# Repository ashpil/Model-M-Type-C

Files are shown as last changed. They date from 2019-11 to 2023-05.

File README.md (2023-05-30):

# Model M Type C
This is a project with the simple goal of recreating the old IBM Model M keyboard controller with modern technologies in mind.

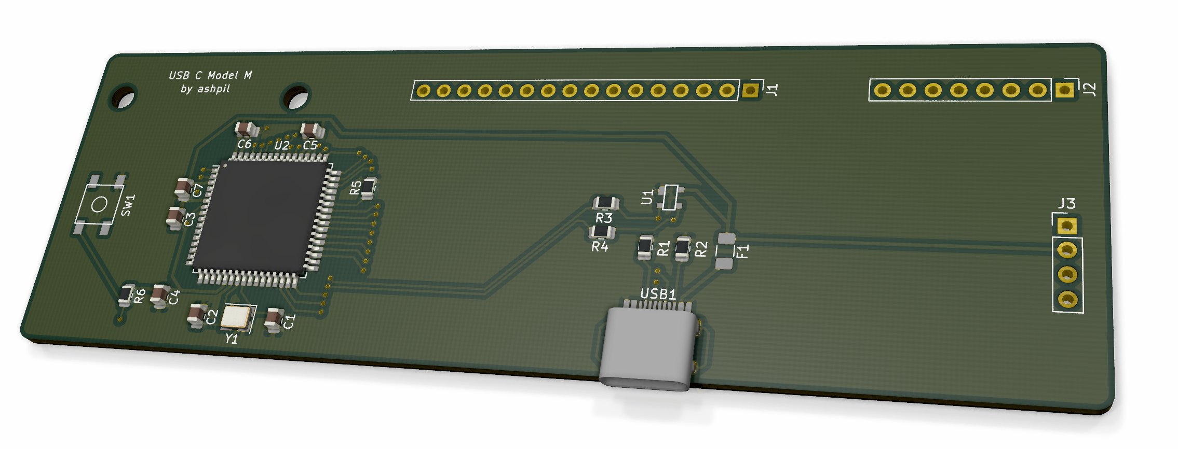
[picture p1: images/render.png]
Board Render


## Motivation
Although the IBM Model M is perhaps the most well-known and popular of old keyboards, it isn't equipped with some modern ameneties we have grown used to enjoying. Key features that the Model M lacks are Windows and Media keys(or, broader, firmware-level repogramability), as well as a hotswappable connection with a modern interface. This controller is designed to bring 21st century features to a 20th century keyboard.

## Goals
- Native USB C
- Hotswappable
- Fully configurable with QMK compatibility
- Less power draw
- Complete reversability

## Usage
Note: If your Model M has two ribbon cables with a 16-12 split rather than the three connectors with 16-8-4 split, see [this](https://github.com/ashpil/Model-M-Type-C-Controller/issues/2) issue.

1. Print the board either using a cheap foreign service such as [JLCPBC](https://jlcpcb.com/ "JLCPBC") for around $6 + shipping, or a domestic service such as [OSH Park](https://oshpark.com/ "OSH Park") for around $35. Someone also seems to be selling a PCB for this on eBay, which is totally a scam for $47.95. Does make me feel flattered, though.
2. Order the components- [part list](https://www.digikey.com/short/p00t8f "part list") from Digikey. USB-C port needs to be bought elsewhere, I recommend [here](https://keeb.io/products/usb-c-port-12-pin-hro-type-c-31-m-12 "usb c hro female port").  $15 total for components. If your LEDs connect via a ribbon, get [this](https://www.digikey.com/short/p012jt "this") instead of the JST 4 pin connector. I used [this](https://www.amazon.com/gp/product/B01787RB40 "usb c cable") cable as a riser cable to connect the controller's USB C port to the side of the keyboard. Unfortunately, due to size conflicts, this cannot be done without a riser cable if you want the external usb c cable to be detachable. This brings total component cost to $25 without shipping.
3. Put it together. It's possible to solder these SMD components manually with a soldering iron, but if you are able to find a hot air gun or a reflow oven, it'll be significantly easier. Reference the visual BOM to see what goes where.
4. 3D print the [USB-C cable dock](usbcdock.stl "usb c dock"). You can mount this on top of the board for it to look near-native. Attach the riser cable to the dock with some hot glue or epoxy.
4. Connect the ribbon cables and LED wires, and mount the PCB in the same way the old PCB was mounted. Attach the USB-C dock on top of that.
5. Install firmware.

## Firmware
This board is fully compatible with QMK. This is a default QMK configuration, so all you need to do is run this from your QMK directory when you are ready:

	make ashpil/modelm_usbc:default:flash
	
Check [here](https://github.com/qmk/qmk_firmware/tree/master/keyboards/ashpil/modelm_usbc "QMK profile") for details.

Alternatively you can use the [Vial](https://get.vial.today/) firmware. Setup is analogous to QMK, clone the Vial repo and run:
	
	make ashpil/modelm_usbc:vial:flash

## Other

If you have any problems/comments, or find anything that could be improved, please submit issue or a pull request!

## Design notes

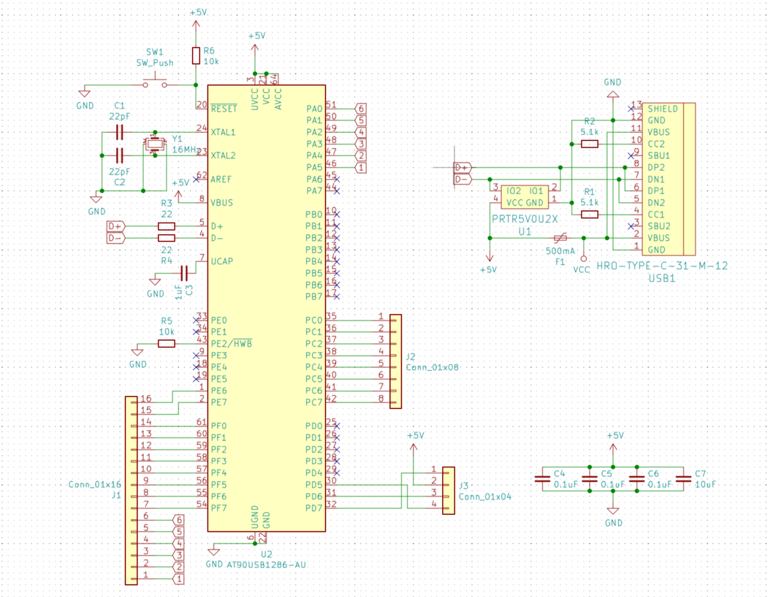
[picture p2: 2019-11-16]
images/schematic.png

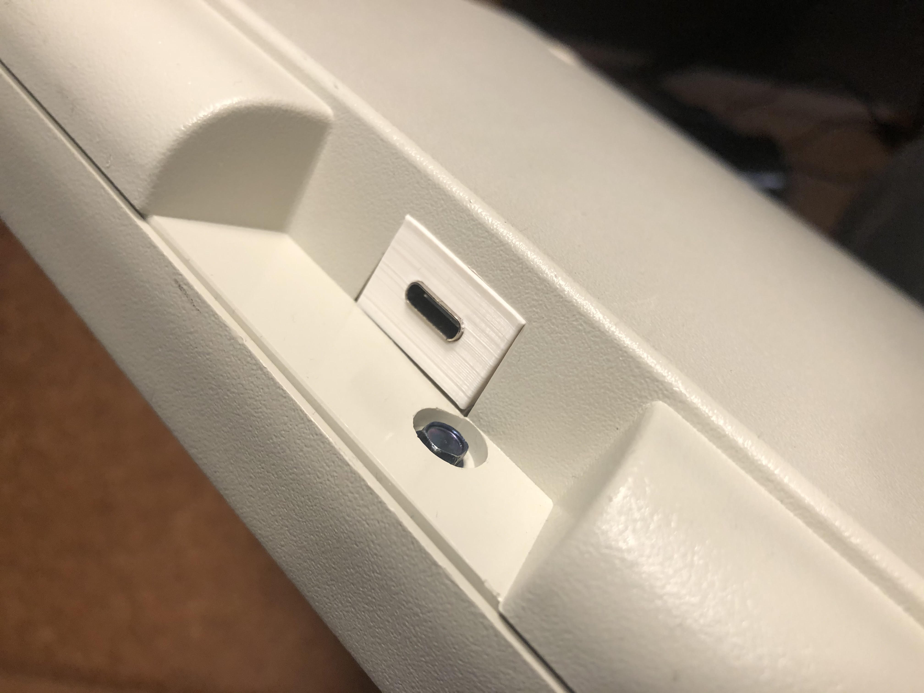
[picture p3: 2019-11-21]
images/usbcport.jpg

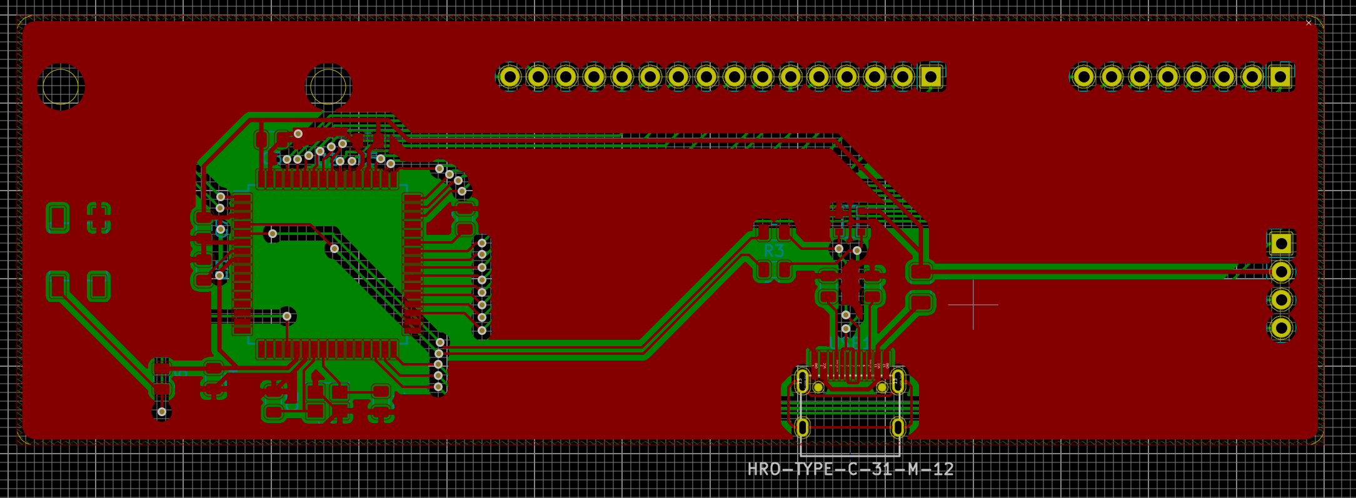
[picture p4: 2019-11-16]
images/layout.png

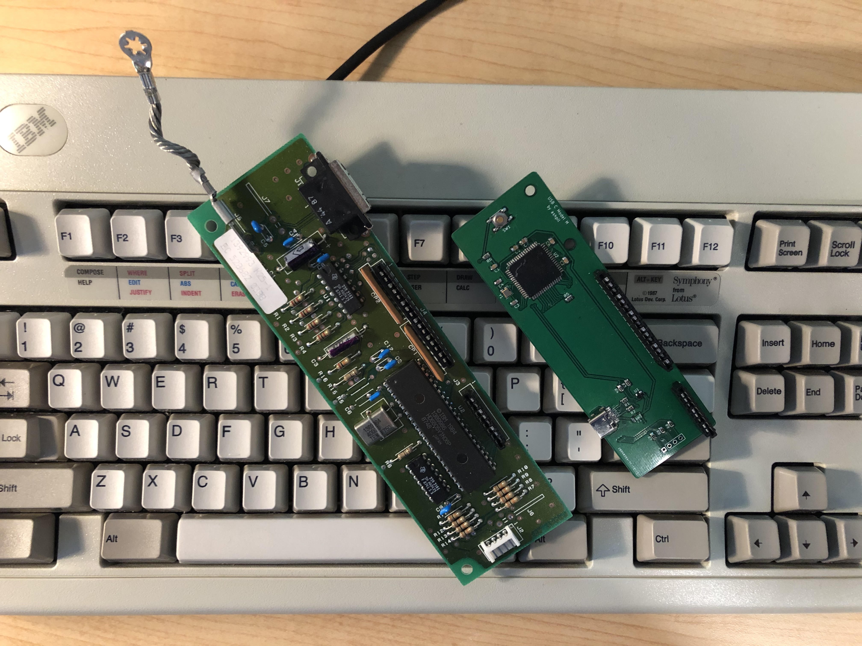
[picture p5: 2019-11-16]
images/oldvsnew.jpg

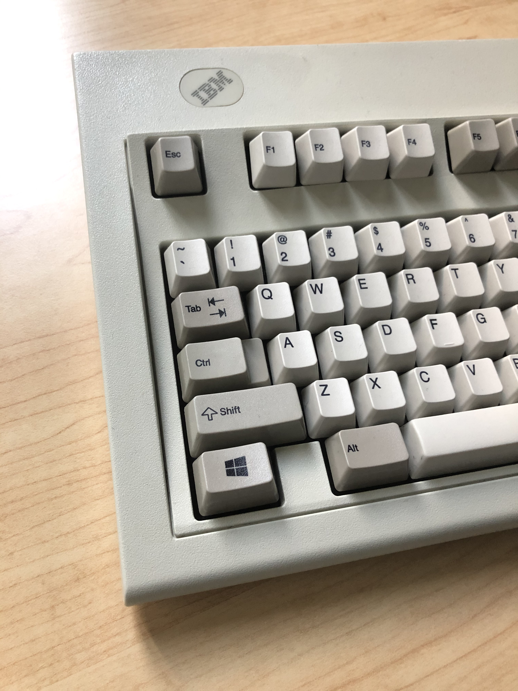
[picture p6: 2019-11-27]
images/windowskey.jpg

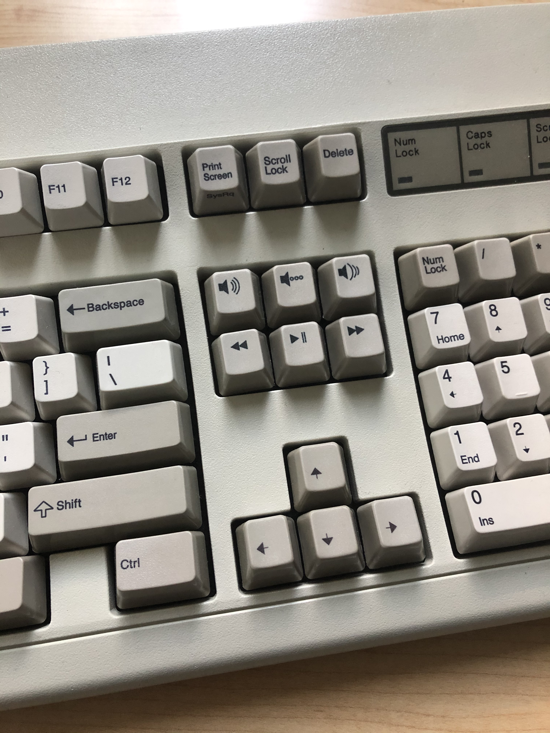
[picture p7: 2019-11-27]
images/mediakeys.jpg

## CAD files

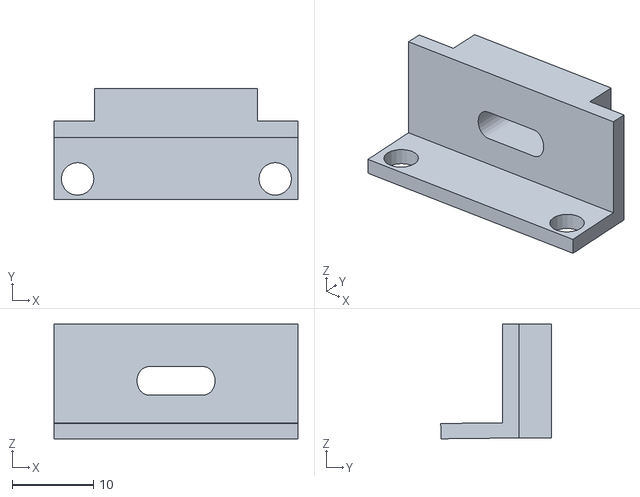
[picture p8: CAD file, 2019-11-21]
usbcdock.stl
30.0 x 13.6 x 14.1

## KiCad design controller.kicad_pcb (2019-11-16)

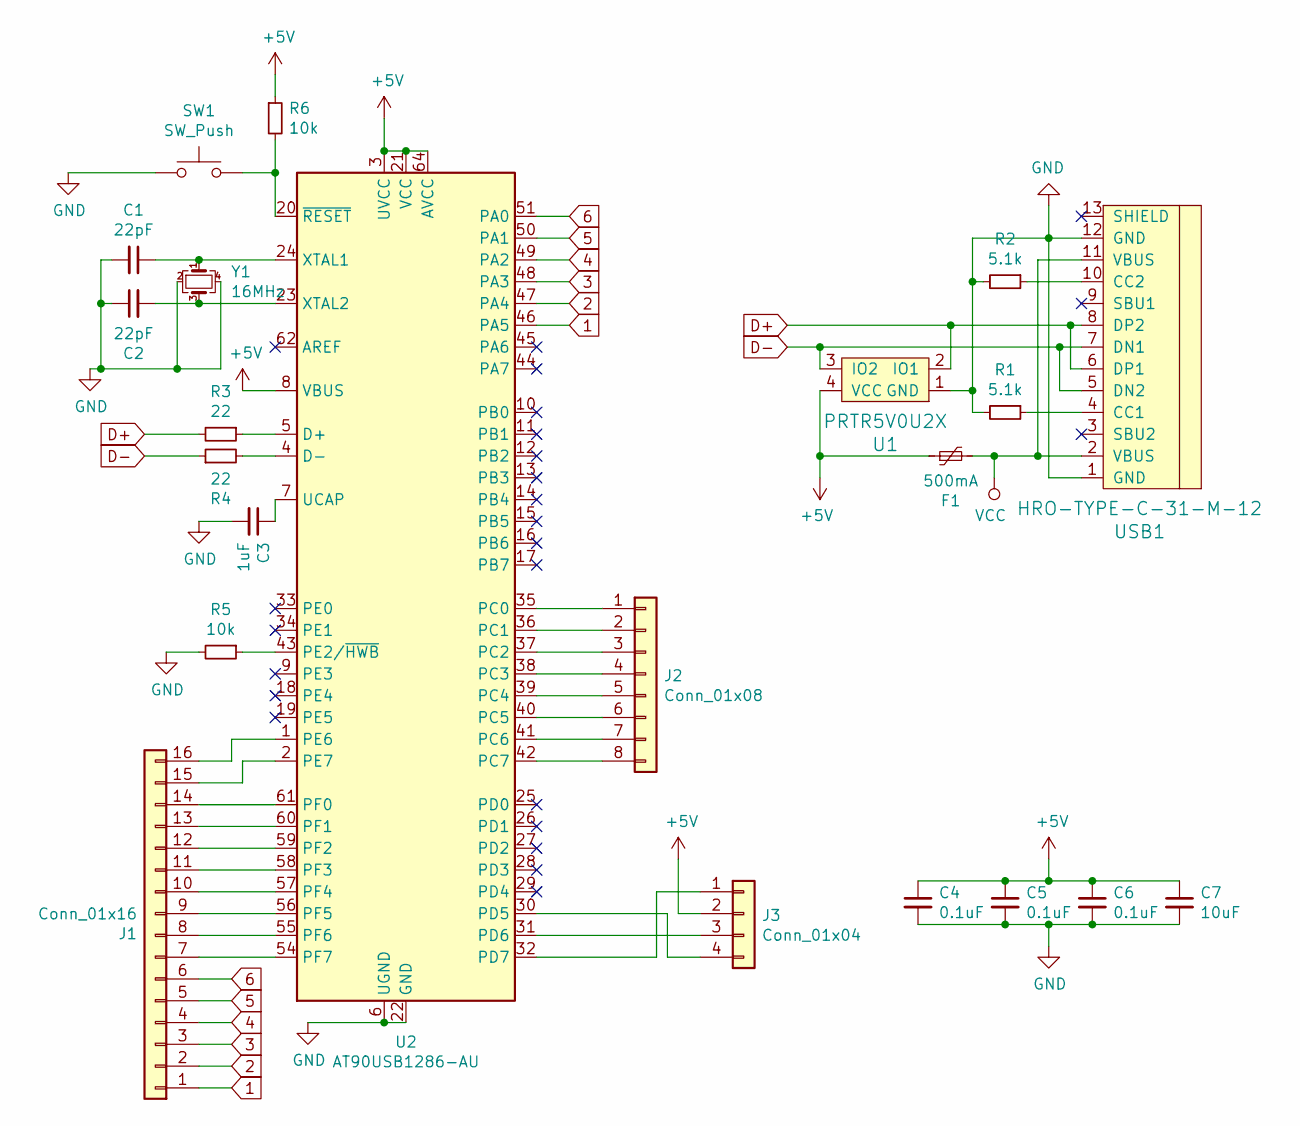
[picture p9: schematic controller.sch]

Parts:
C1, C2: 22pF; C_0805_2012Metric
C3: 1uF; C_0805_2012Metric
C4, C5, C6: 0.1uF; C_0805_2012Metric
C7: 10uF; C_0805_2012Metric
F1: 500mA; Fuse_1206_3216Metric
J1: Conn_01x16; PinHeader_1x16_P2.54mm_Vertical
J2: Conn_01x08; PinHeader_1x08_P2.54mm_Vertical
J3: Conn_01x04; PinHeader_1x04_P2.54mm_Vertical
R1, R2: 5.1k; R_0805_2012Metric
R3, R4: 22; R_0805_2012Metric
R5, R6: 10k; R_0805_2012Metric
SW1: SW_Push; SKQG-1155865
U1: PRTR5V0U2X; SOT143B
U2: AT90USB1286-AU; TQFP-64_14x14mm_P0.8mm
USB1: HRO-TYPE-C-31-M-12; HRO-TYPE-C-31-M-12-HandSoldering
Y1: 16MHz; Crystal_SMD_3225-4Pin_3.2x2.5mm

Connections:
1: J1.1, U2.46 (PA5)
2: J1.2, U2.47 (PA4)
3: J1.3, U2.48 (PA3)
4: J1.4, U2.49 (PA2)
5: J1.5, U2.50 (PA1)
6: J1.6, U2.51 (PA0)
+5V: C4.1, C5.1, C6.1, C7.1, F1.1, J3.2, R6.1, U1.4 (VCC), U2.3 (UVCC), U2.8 (VBUS), U2.21 (VCC), U2.52 (VCC), U2.64 (AVCC)
D+: R3.2, U1.2 (IO1), USB1.6 (DP1), USB1.8 (DP2)
D-: R4.1, U1.3 (IO2), USB1.5 (DN2), USB1.7 (DN1)
GND: C1.2, C2.1, C3.2, C4.2, C5.2, C6.2, C7.2, R1.2, R2.2, R5.2, SW1.1, U1.1 (GND), U2.6 (UGND), U2.22 (GND), U2.53 (GND), U2.63 (GND), USB1.1 (GND), USB1.12 (GND), Y1.2, Y1.4
unnamed: C1.1, U2.24 (XTAL1), Y1.1
unnamed: C2.2, U2.23 (XTAL2), Y1.3
unnamed: C3.1, U2.7 (UCAP)
unnamed: J1.7, U2.54 (PF7)
unnamed: J1.8, U2.55 (PF6)
unnamed: J1.9, U2.56 (PF5)
unnamed: J1.10, U2.57 (PF4)
unnamed: J1.11, U2.58 (PF3)
unnamed: J1.12, U2.59 (PF2)
unnamed: J1.13, U2.60 (PF1)
unnamed: J1.14, U2.61 (PF0)
unnamed: J1.15, U2.2 (PE7)
unnamed: J1.16, U2.1 (PE6)
unnamed: J2.1, U2.35 (PC0)
unnamed: J2.2, U2.36 (PC1)
unnamed: J2.3, U2.37 (PC2)
unnamed: J2.4, U2.38 (PC3)
unnamed: J2.5, U2.39 (PC4)
unnamed: J2.6, U2.40 (PC5)
unnamed: J2.7, U2.41 (PC6)
unnamed: J2.8, U2.42 (PC7)
unnamed: J3.1, U2.32 (PD7)
unnamed: J3.3, U2.31 (PD6)
unnamed: J3.4, U2.30 (PD5)
unnamed: R1.1, USB1.4 (CC1)
unnamed: R2.1, USB1.10 (CC2)
unnamed: R3.1, U2.5 (D+)
unnamed: R4.2, U2.4 (D-)
unnamed: R5.1, U2.43 (PE2/~HWB)
unnamed: R6.2, SW1.2, U2.20 (~RESET)
VCC: F1.2, USB1.2 (VBUS), USB1.11 (VBUS)

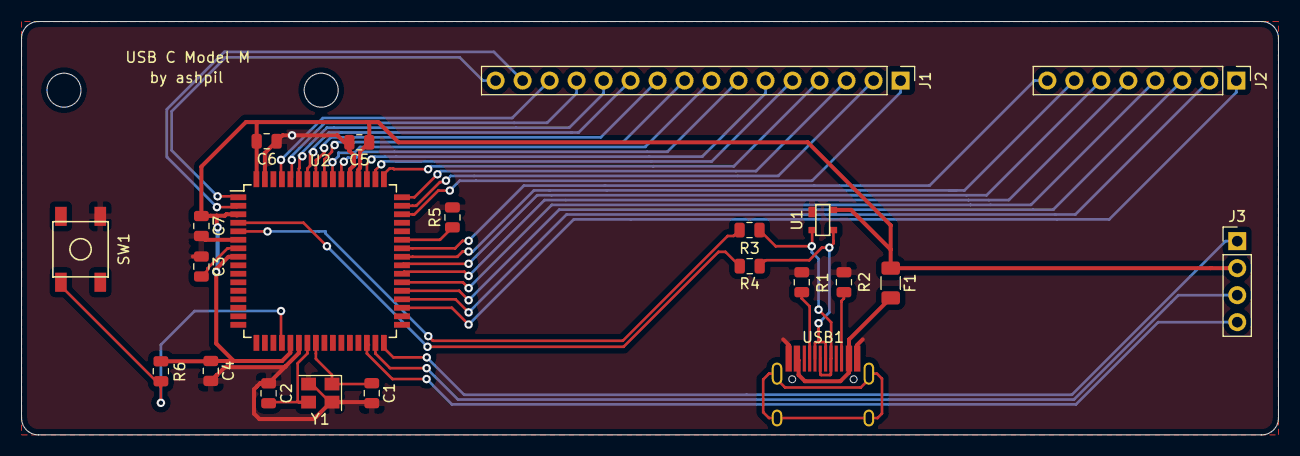
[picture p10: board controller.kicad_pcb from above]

Board: 2 copper layers, 118.3 x 38.9 mm, 22 parts (0 on the bottom side), 41 nets.

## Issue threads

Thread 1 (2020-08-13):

OSH Park PCB:  This project is owned by another user and has not been shared.

ntrischi, 2020-08-13:
I'm attempting to upload your PCB to OSH Park. My OSH Park order cannot be completed as the project has not been shared.

ashpil, 2020-08-13:
That is interesting, I wonder why OSH Park has such a system set up and whether it is effective.

Try again now, I think I cleared the project from my account.

ntrischi, 2020-08-13:
Same Issue as before. I'm uploading the _controller.kicad_pcb_ to OSH Park. Here's a screenshot https://imgur.com/a/kPDmbOb

ntrischi, 2020-08-14:
I was able to place my order on OSH Park. The issue seem to resolve.

ashpil, 2020-08-14:
That's good, thanks for notifying me about this! I'd be very happy to hear about your experience with the controller and any feedback you might have.

Closed 2020-08-14.

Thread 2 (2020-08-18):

IBM Model M Keyboard Part #1391401 Incompatible

ntrischi, 2020-08-18:
My IBM Model M uses a 12-pin J3 connector instead of the 8-pin connector. The USB C controller PCB should combine the J3 and J2 headers. I have uploaded an image of my current IBM PS/2 controller PCB. https://imgur.com/a/fwaWYjc

Using the existing USB-C PCB, it might be possible to solve this issue with an 12-pin connector and wire lines to the 4-pin J3 connector.

ntrischi, 2020-08-18:
Here's the 12-pin connector to use. https://www.digikey.com/product-detail/en/te-connectivity-amp-connectors/6-520315-2/A123179-ND/1137020

ashpil, 2020-08-18:
Thanks for reporting this! I'll link this issue in the readme, in case someone runs into a similar problem.

Once I have some time I'll see if my design can be changed to allow both style of controllers to work without workarounds.

ntrischi, 2020-10-20:
The controller is compatible. It is possible to use a 12-pin connector and solder wires to the J2 header.

Closed 2020-10-20.

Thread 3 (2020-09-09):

Is this compatible with the 122-key ("M122") Model M keyboards?

EntitySK, 2020-09-09:

EntitySK, 2020-09-09:
Closed. It will not be compatible. The IBM M122 keyboards have a different key matrix: [Matrix Maps + Charts + Firmware](https://phosphorglow.net/2015/06/24/matrix-maps-charts/).

ashpil, 2020-09-10:
Sorry I didn't get to take a look a this! Yeah, it looks like it doesn't work for the 122 key, though I reckon it wouldn't be too hard to modify to get it to work.

EntitySK, 2020-09-10:
Mhm! According to your schematic, it looks like it would just require a few more GPIO. I'm looking into designing something similar to your board with an nrf52840 module for added bluetooth. Your design is very helpful!

ashpil, 2020-09-10:
Let me know if you make any progress with that, I'm interested in making something wireless as well!

Closed 2020-09-09.

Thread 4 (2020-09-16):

No device present?

ntrischi, 2020-09-16:
How did you debug the board once it was soldered together? I am getting the following error below.

```
* The firmware size is fine - 14128/122880 (11%, 108752 bytes free)
dfu-programmer: no device present.
ERROR: Bootloader not found. Trying again in 5s.
dfu-programmer: no device present.
```

ashpil, 2020-09-16:
Do you experience a similar problem if you use QMK? I haven't tried it with `dfu-programmer`.

ashpil, 2020-09-16:
Even if some of the soldering didn't stick right, you should be able to detect the board. The vast majority of the connections just go
to the keys and aren't actually important for the computer to detect the board. If you don't think it's a software issue, I guess I'd just try to see if you can find anything unusual with a multimeter, especially around the parts that are relevant for USB connection.

ashpil, 2020-09-16:
Sorry for the multiple comments, it's been quite a bit since I worked on this project so I'm remembering stuff!

There's also a button, and pressing it might produce some sort of result when it is plugged into a computer. Might be worth trying.

ntrischi, 2020-09-16:
No worries. I appreciate the quick response. I followed the BOM closely and noticed that most of the components did not have a polarity. The only component that could be soldered incorrectly is the Crystal_SMD_3225 as the pin-out was not straightforward. Additionally, I ran `make ashpil/modelm_usbc:default:flash` from within the qmk_firmware directory. Is `dfu-programmer` not correct here?

ashpil, 2020-09-16:
If I remember correctly, QMK is able to handle flashing alone, without any other software.

ashpil, 2020-09-22:
Any luck on this, @ntrischi?

ntrischi, 2020-10-04:
No luck so far. I am using the latest version of QMK. I am still getting the following error below.
```
dfu-programmer: no device present.
ERROR: Bootloader not found. Trying again in 5s.
```
I'm attempting to flash the device with the ribbon cables and LED wires connected. Any tips on debugging the PCB?

ashpil, 2020-10-05:
If you use the graphical version of QMK, you should see something like this if you play around with the reset button:

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

See the yellow

ntrischi, 2020-10-05:
Interesting, I'll give the graphical version of QMK a try.

ashpil, 2020-10-05:
>
>
> Interesting, I'll give the graphical version of QMK a try. Does the ribbon cables and LED wires need to be connected from the keyboard in order to flash the device?

Don't believe they do.

ntrischi, 2020-10-08:
No luck with the graphical version of QMK. Probably a short or a bad component.
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

ashpil, 2020-10-08:
Can you send pictures of the board? @ntrischi

ntrischi, 2020-10-08:
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

ashpil, 2020-10-10:
That does look a bit messy, there might be a possibility of a short. I do commend the US-local OSH Park, though! :p

If you can get hands on a multimeter, you could ensure there are no shorts. Make sure that all adjacent pins are completely separate and do not share current. There could be troubling points in the USB-C and processor connections. Also you could ensure that things that are supposed to be connected, are indeed connected - for example, ensure that the current on a specific USB-C pin leads to the intended pin on the processor.

This is what I did to debug my own board, and once I put a multimeter to it, it was clear where the issues were, and I could fix it.

@ntrischi

ntrischi, 2020-10-11:
Unfortunately, the USB connector broke off on my board and the pads ripped off. So, I'm starting over. Luckily, I have 2 more boards and the parts to build another. Hopefully, the second one is the charm. Thanks for you help and the response.

ashpil, 2020-10-11:
Of course! Let me know how that goes. If you can use a reflow oven at a nearby hackerspace or university, the detailed soldering becomes much easier. That's how I did mine.

ntrischi, 2020-10-16:
I was able to flash the device.
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

ashpil, 2020-10-16:
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

Wonderful! Please open an issue/PR/let me know if you have any ideas for improvements!

Closed 2020-10-16.

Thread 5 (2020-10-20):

Multiple keys typed

ntrischi, 2020-10-20:
Using the default firmware, typing the key 'm' will print 'nm'. The 'enter' key will print a space and newline. Just wondering if you encountered this type of issue before?

ashpil, 2020-10-20:
That's not an issue that I've experienced. There's a chance your routes for n/m and enter/newline soldered together. See if they are connected with a multimeter.

Closed 2023-05-30.

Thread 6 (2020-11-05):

Unused Pins Breakout

posicat, 2020-11-05:
Would it be possible to break out the remaining pins to headers on the board?

Specifically my idea is that it could be paired with a Raspberry Pi Zero W board, and along with normal keyboard mode, the keyboard could also operate as a portable computer, and allow for complex macroing beyond what QMK allows (event based keyboard actions, etc).   Also of course adding ws2812b LEDs in place of the standard Num./Caps/Scroll lock LEDs, and possibly adding backlight to the whole keyboard.

ashpil, 2020-11-05:
That's a very cool idea! The monitor is what always stops me from projects like this. :(

It wasn't designed for that in mind, but it's certainly _possible_. You're very welcome to submit a PR with the necessary modifications, it shouldn't be too hard from what I understand.

posicat, 2020-11-06:
I've only used EasyEDA for PBC design, so I'll have to figure out how to get these schematics loaded into something to edit that.  As for the QMK code, that shouldn't be as hard to put in a switch to route IO to the serial port and back, but I'll have to take time to figure that out as well.  I'm also considering a PCB for the Model M that would take a Pi 4 Compute Module, which would give it a really powerefull processor, but I'm not at all familiar with PCB routing for high speed signals like the PCIe bus.

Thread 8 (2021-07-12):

Strange glitch in the README

eric-s-raymond, 2021-07-12:
At https://github.com/ashpil/Model-M-Type-C there is the following text: "Note: If you have the Model M #1391401 (tenkeyless), see this issue."

This raised an alarm in my mind. I have a 1391401 (made in 1988 and it is absolutely not tenkeyless. There are other tenkeyless variants of the M, you can find them if you look for "Space Saver Keyboard" in the variants list at the Wikipedia entry, but no M with that part number has ever been an SSK.

Then I read the issue, and it never mentions the 1391401 or the tenkeyless layout.  It's about dealing with the later Lexmark membranes with a 16-12 connectors.  I opened up my 1391401 and verified that it has the 16-8-4 connectors your board is designed for.

I suppose it is just barely possible that later manufacturing revisions 1391401 could have 16-12 connectors, but you can avoid the whole issue by not mentioning the 1391401 at all.  Suggested replacement text:

"If your M has two ribbon cables with a 16-12 split rather than the three connectors with 16-8-4 split, see the following issue"

ashpil, 2021-07-14:
Good catch, I'm not sure why I ended up putting tenkeyless in there. Fixed, thanks!

Closed 2021-07-20.

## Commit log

2019-10-29 basic files
    [controller.kicad_pcb, controller.sch]
2019-10-29 configuring kicad
2019-10-29 basic schematic and more footprints
2019-10-29 footprints assigned
    [controller.sch]
2019-10-30 changed to at90usb1286 and cleanup
    [controller.sch]
2019-10-31 pcb design
    [controller.kicad_pcb, controller.sch]
2019-10-31 completion?! finished all circuitry
    [controller.kicad_pcb]
2019-10-31 misc tweaks for shield and usb pathing
    [controller.kicad_pcb, controller.sch]
2019-10-31 clarified resistor value
    [controller.kicad_pcb, controller.sch]
2019-10-31 made gound/5v/usb routing neater
    [controller.kicad_pcb]
2019-10-31 generated gerbers
    [controller-B_Cu.gbr, controller-B_Mask.gbr, controller-B_Paste.gbr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]
2019-11-01 part list added
    [controller.kicad_pcb]
2019-11-15 rev 2
    Adjusted ucb-c location, fixed grounding error, changed some sizes to be more snug
    [controller-B_Cu.gbr, controller-B_Mask.gbr, controller-B_Paste.gbr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]
2019-11-16 fixed LED connector
    [controller.kicad_pcb, controller.sch]
2019-11-16 final touches, cleanup
    [controller-B_Cu.gbr, controller-B_Mask.gbr, controller-B_Paste.gbr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]
2019-11-21 updated images and instructions to include 3d print
    [usbcdock.stl]
